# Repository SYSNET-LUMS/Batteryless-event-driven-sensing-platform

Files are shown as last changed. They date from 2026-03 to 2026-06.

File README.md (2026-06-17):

# Motion-Coupled Sensing: When the State Change Powers Its Own Sensing

A self-powered IoT platform that harvests kinetic energy from mechanical access events — bin lids, room doors, and office cabinet hinges — to power and transmit sensor readings with no batteries and no scheduled maintenance.

---

## How It Works

Objects whose state changes only through a mechanical action carry enough kinetic energy in that motion to power both a sensor reading and a LoRa uplink. The system wakes only when there is something to report, and the event itself supplies the energy to do it. There is no polling, no sleep schedule, and no battery to replace.

An electromagnetic harvester — a DC motor in generator mode driven through a compact gear train — is retrofitted to the hinge or lid mechanism without any structural modification to the host object.

## Repository Structure

```
├── firmware/
│   ├── sensor-node/                  # Sensor node and gateway firmware, packet-layout SVG
│   └── bin_unit_field_testing/       # Bin lid characterization firmware + serial data logger
├── hardware/
│   ├── harvestor_cad/                # STEP, STL, SLDPRT, DXF files; CAD modeling video
│   └── pcb/                          # PCB schematic, layout, EPRO project, netlist
├── bin_depth_analysis/
│   ├── Images/                       # Per-run averaged depth and RGB frames (run1–50)
│   └── Wall Masks/                   # Masked depth averages for wall-plane isolation (run1–15)
└── media/
    └── images/
        ├── bin-unit/                 # Bin unit build and deployment photos
        ├── door-unit/                # Door unit build photos
        ├── cabinet-unit/             # Cabinet unit build photos
        └── harvestor.png             # Harvester overview image
```

---

## Results at a Glance

| Deployment | Actuations | Transmission Reliability |
|:---|---:|---:|
| Waste Bins — 5 campus locations | 5,945 | **99.3%** |
| Room Doors | 1870 | **92%** |
| Office Cabinets | 1636 | **94%** |

---

## Harvester

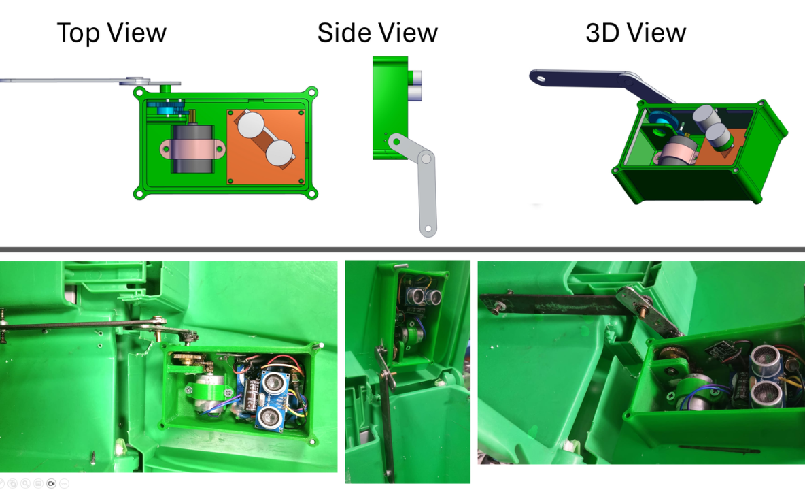
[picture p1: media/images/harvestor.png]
Harvester


| Parameter | Value |
|:---|:---|
| Generator | 24V DC motor (generator mode) |
| Gear Train | 3-stage spur, 1:42.6 ratio |
| Storage | 1000 µF capacitor |
| Gating | Mercury tilt switch + SS34 Schottky diode |

CAD source files (STEP, STL, SolidWorks SLDPRT, DXF drawings, and drawing PDF) are in [`hardware/harvestor_cad/`](hardware/harvestor_cad/).

---

## Sensor Node

| Block | Components |
|:---|:---|
| Sensing | HC-SR04 ultrasonic sensor |
| Compute | ATmega328P MCU, MP2307 buck converter (3V rail) |
| Communication | RA-02 LoRa module (Semtech SX1278) |

### PCB

| Schematic | Layout |
|:---:|:---:|
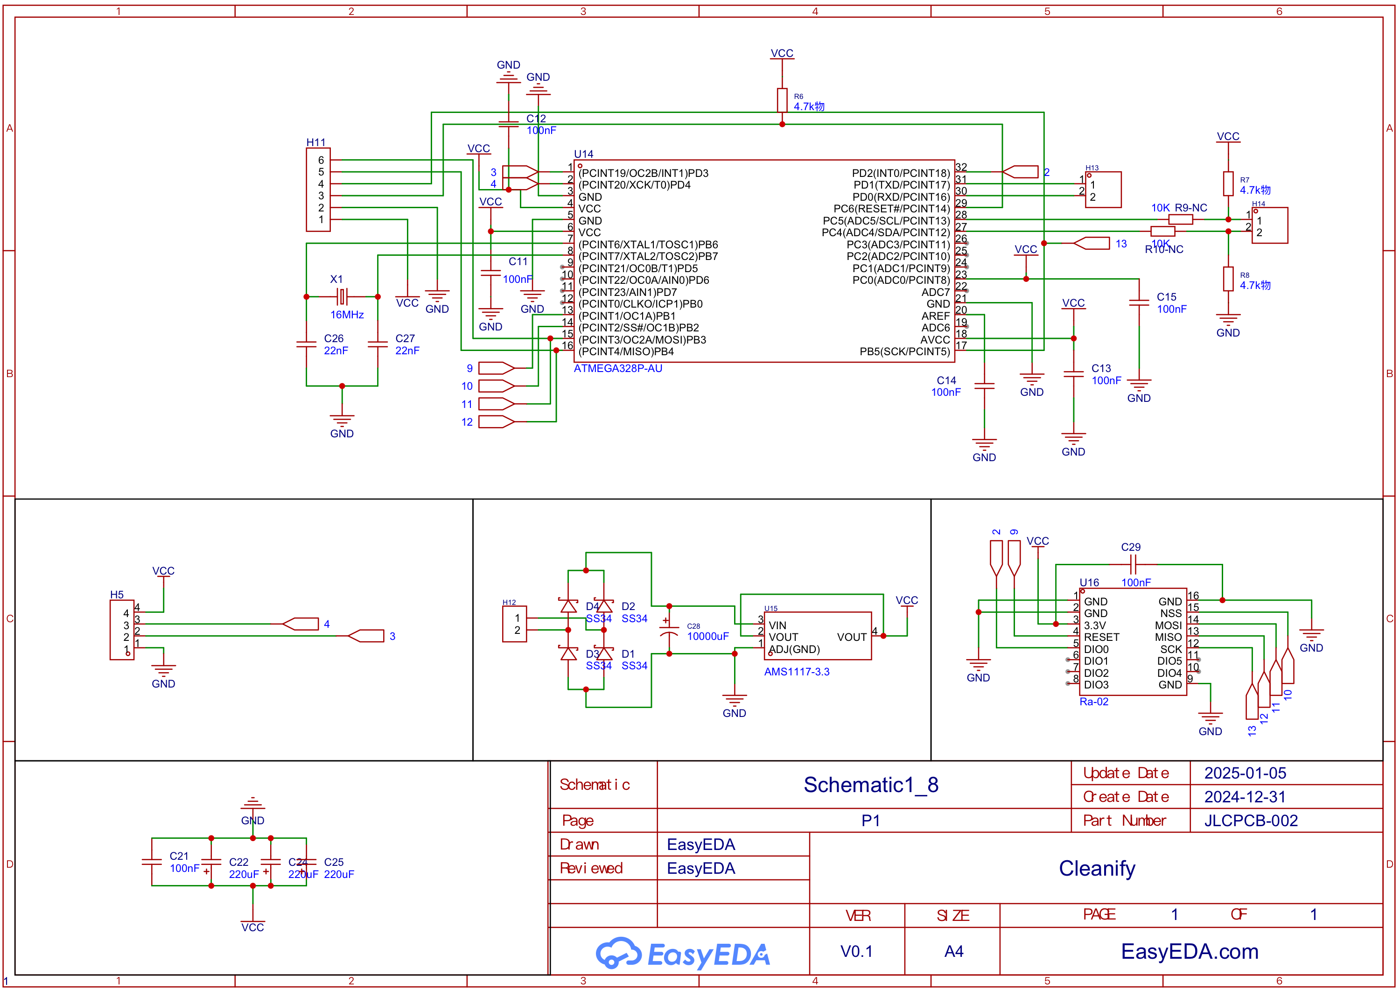
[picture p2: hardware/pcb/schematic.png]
Schematic
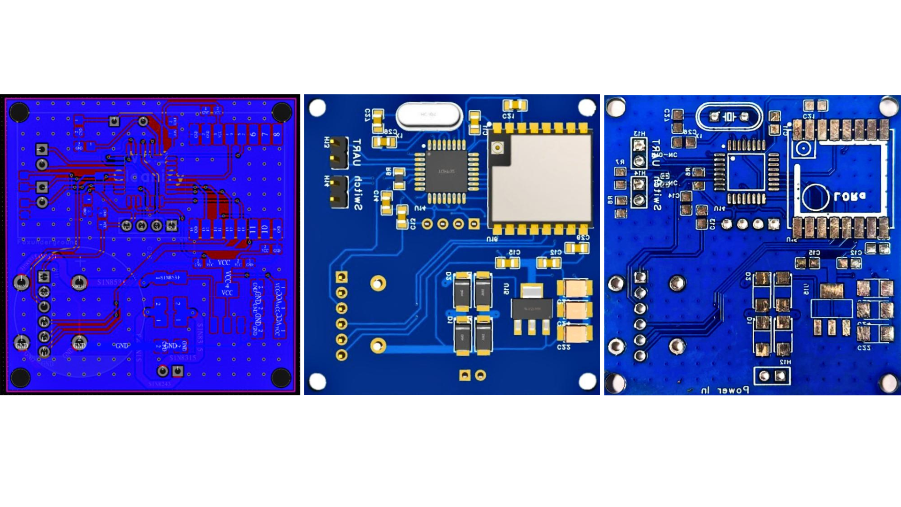
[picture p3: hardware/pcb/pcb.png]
PCB Layout
|  |  |

Design files (EPRO project, netlist, schematic PDF) are in [`hardware/pcb/`](hardware/pcb/).

---

## Form Factors

### Waste Bin

Measures fill level via ultrasonic ranging on every lid open. Deployed across 5 campus locations under real-world conditions (18–38°C, 40–85% humidity, occasional rainfall).

| | | |
|:---:|:---:|:---:|
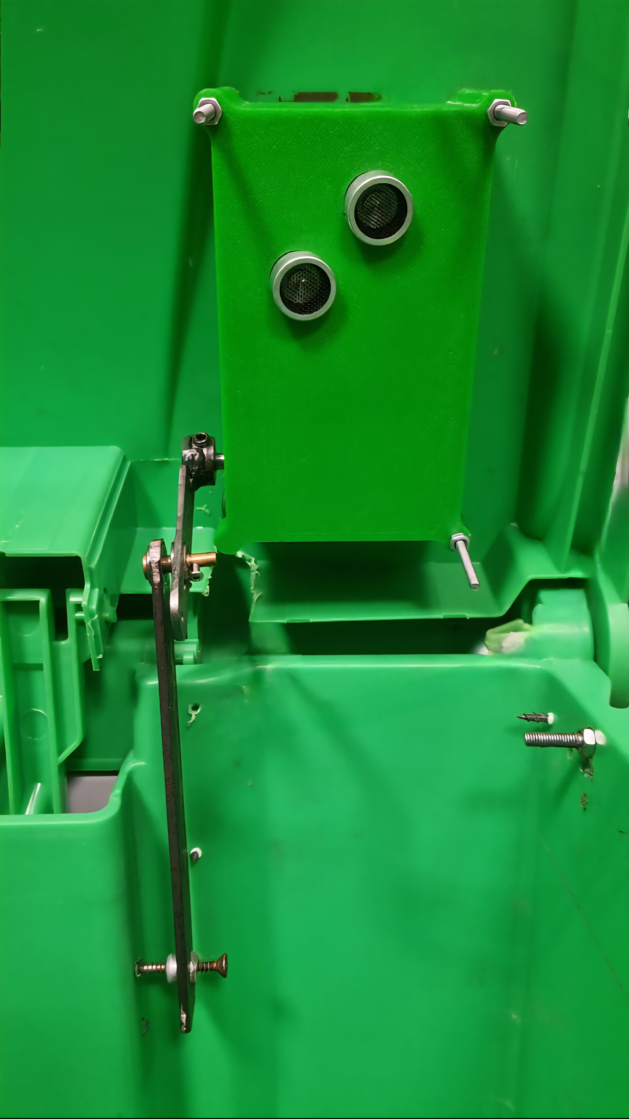
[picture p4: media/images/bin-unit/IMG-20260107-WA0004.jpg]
Bin unit
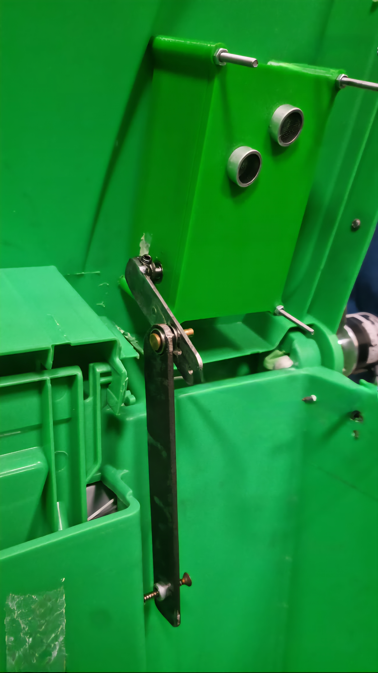
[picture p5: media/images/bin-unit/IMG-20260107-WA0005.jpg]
Bin unit
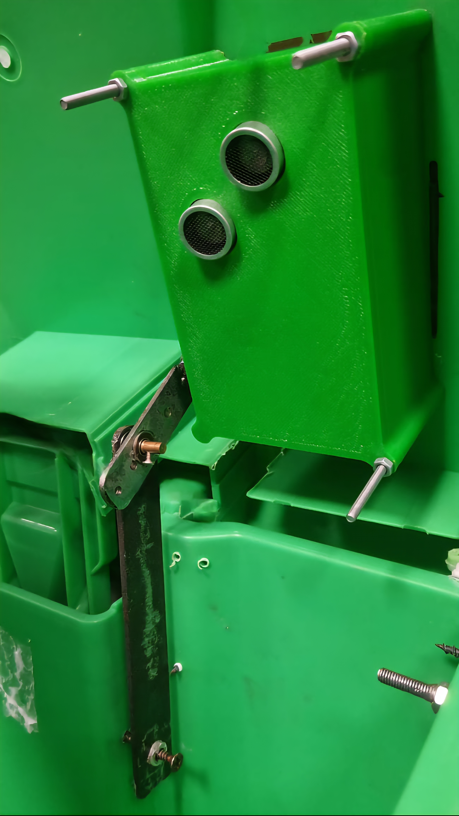
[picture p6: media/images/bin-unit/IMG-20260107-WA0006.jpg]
Bin unit
|  |  |  |
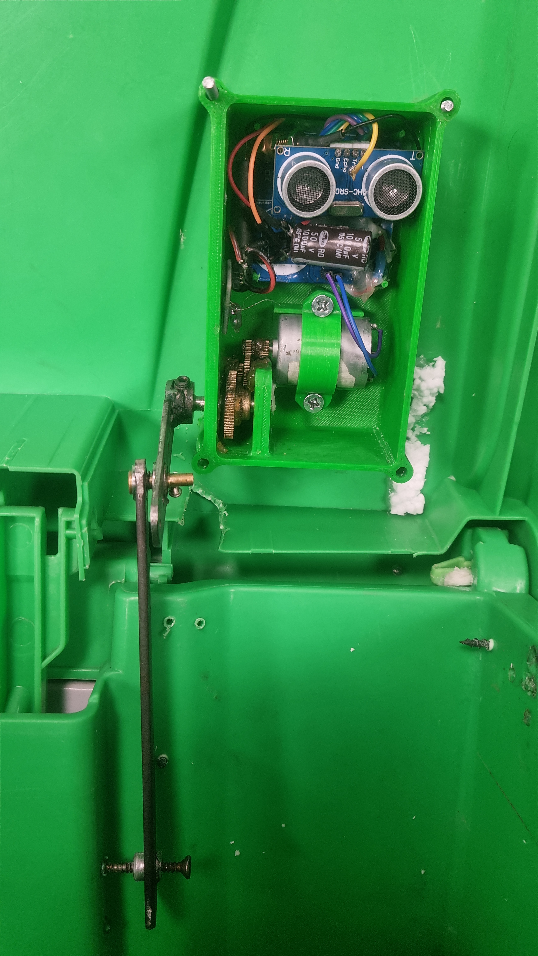
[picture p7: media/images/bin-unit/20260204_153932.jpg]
Bin unit
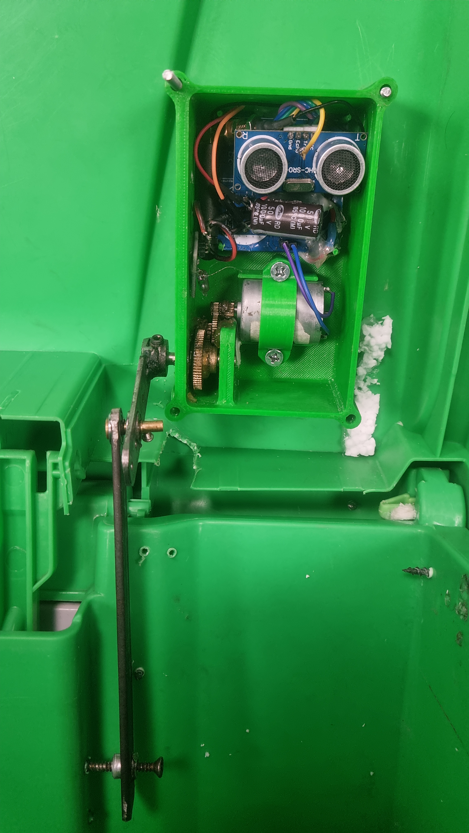
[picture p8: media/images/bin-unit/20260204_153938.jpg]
Bin unit
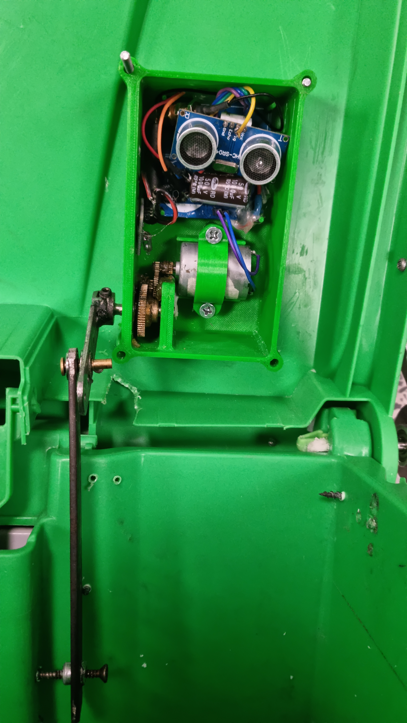
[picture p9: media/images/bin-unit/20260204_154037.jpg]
Bin unit
|  |  |  |

### Room Door

Retrofit mounted to the door hinge. Reports each door swing as an access event.

| | | | |
|:---:|:---:|:---:|:---:|
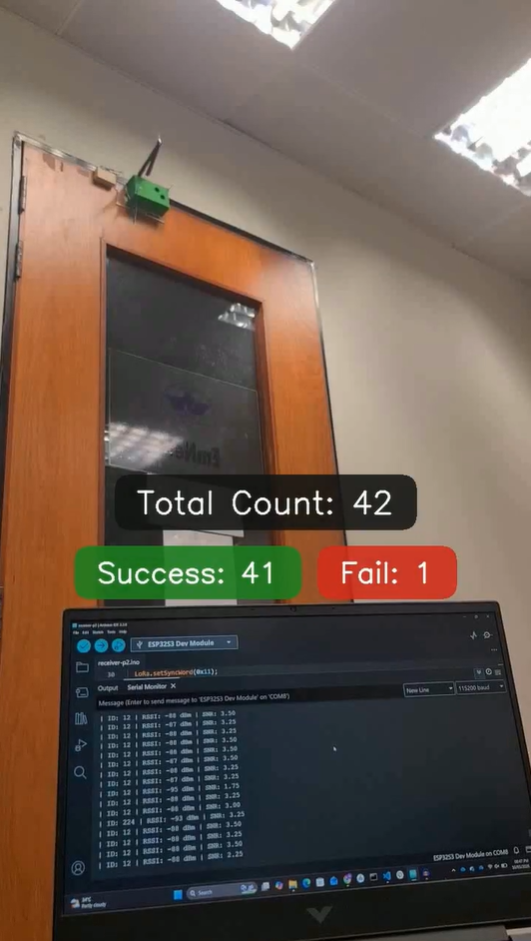
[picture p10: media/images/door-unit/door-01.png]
Door unit
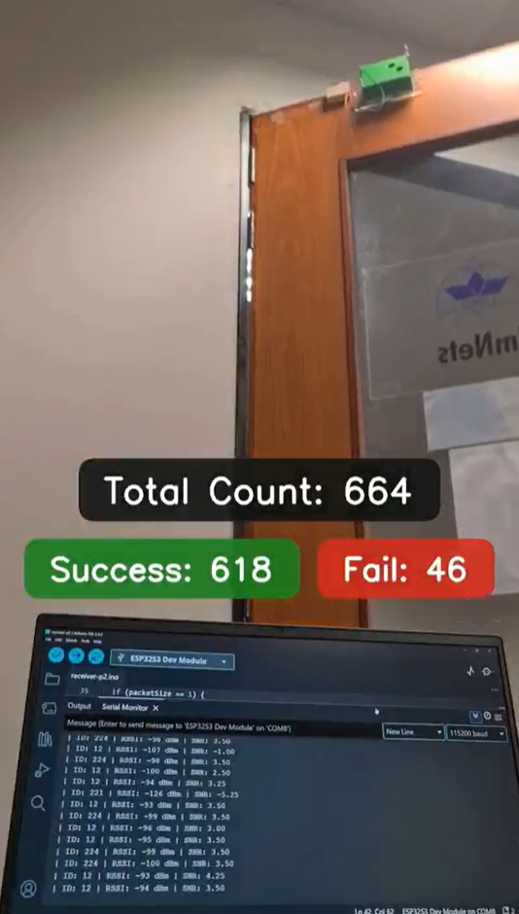
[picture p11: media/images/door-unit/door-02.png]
Door unit
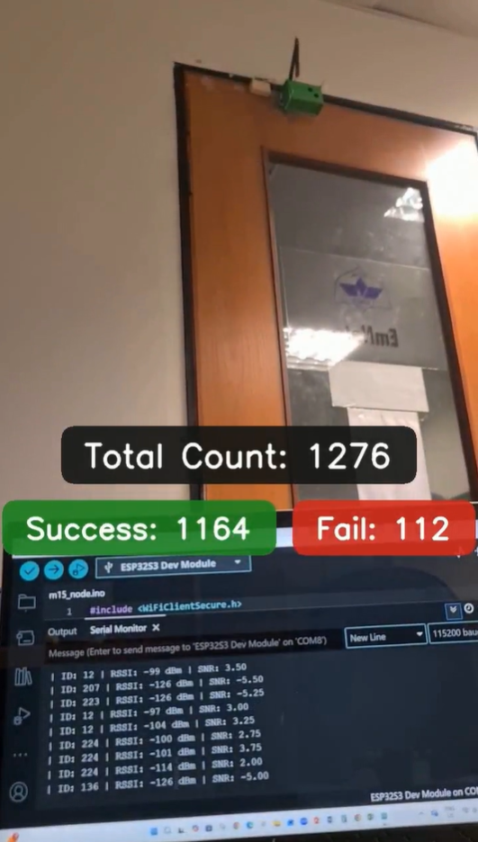
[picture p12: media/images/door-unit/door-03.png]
Door unit
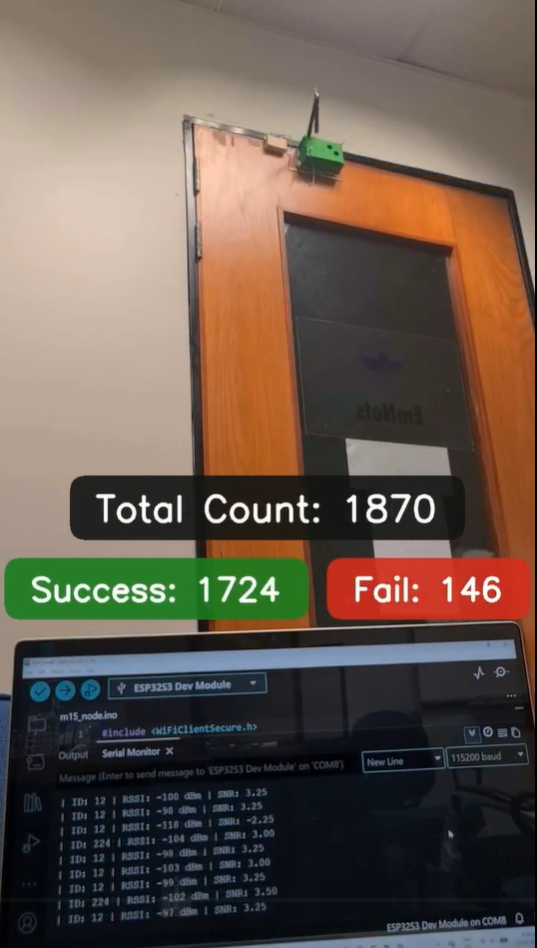
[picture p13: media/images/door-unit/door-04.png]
Door unit
|  |  |  |  |

[Watch full trial on Drive](https://shorturl.at/BA1z8)

### Office Cabinet

Harvester mounted on the cabinet hinge. Reports each cabinet open as an access event.

| | | | |
|:---:|:---:|:---:|:---:|
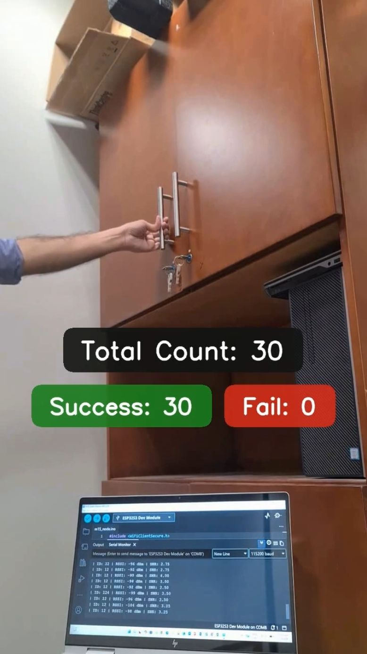
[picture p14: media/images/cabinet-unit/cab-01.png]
Cabinet unit
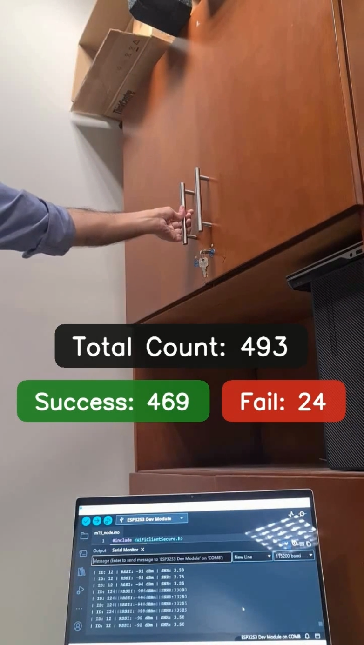
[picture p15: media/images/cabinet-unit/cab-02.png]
Cabinet unit
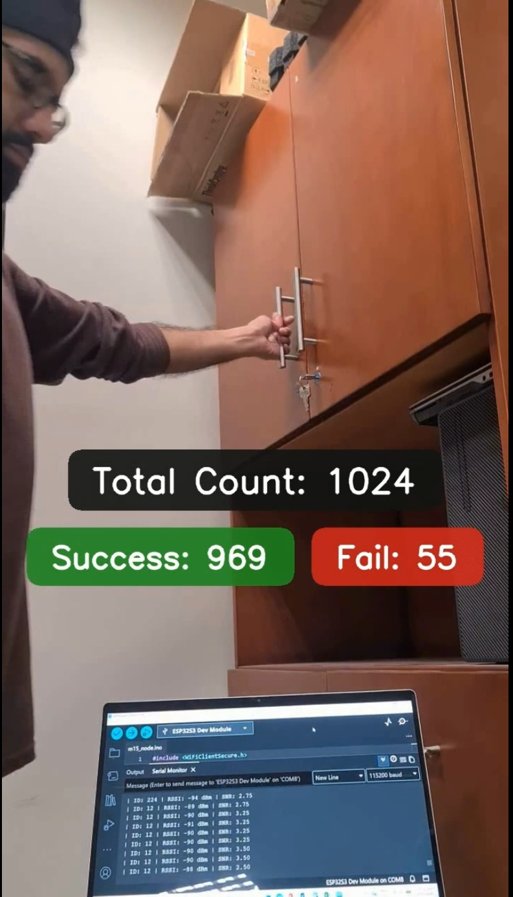
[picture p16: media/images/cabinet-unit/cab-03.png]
Cabinet unit
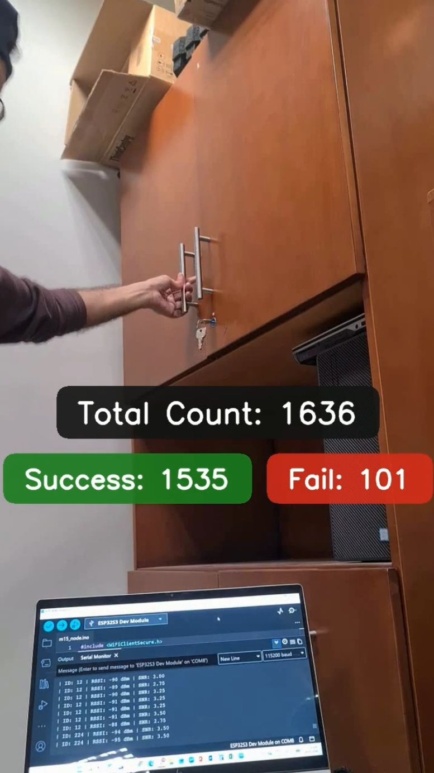
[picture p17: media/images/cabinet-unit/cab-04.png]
Cabinet unit
|  |  |  |  |

[Watch full trial on Drive](https://shorturl.at/NqOQz)

---

## Harvester Stress Testing — 10,000 Iterations

Standalone module run to characterise mechanical durability before field deployment.

| | | | |
|:---:|:---:|:---:|:---:|
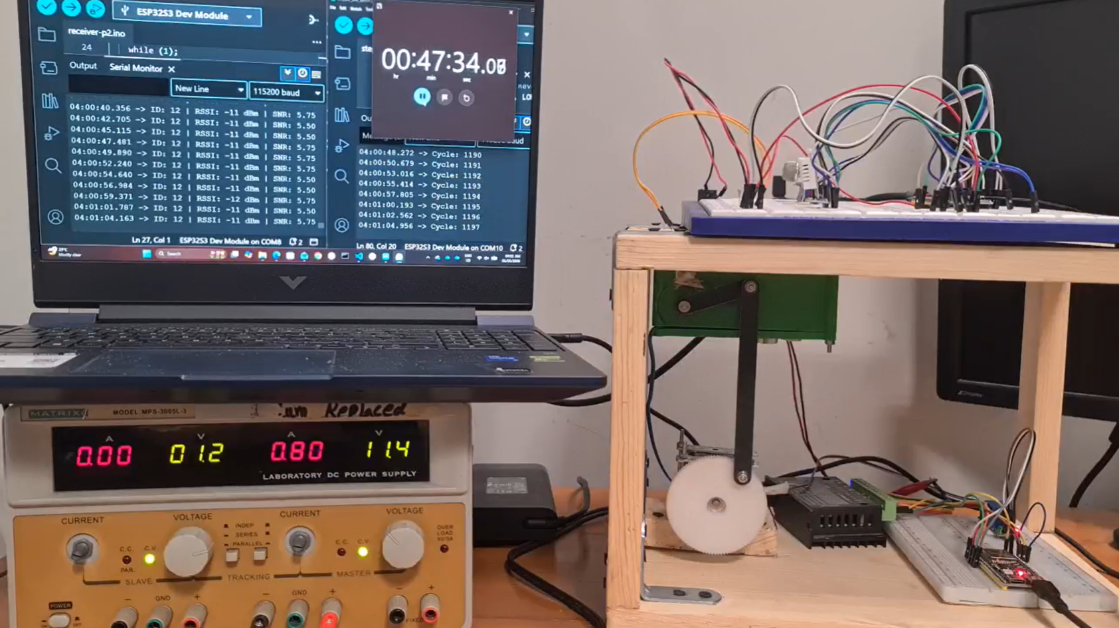
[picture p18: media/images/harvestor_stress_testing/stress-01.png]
Stress test
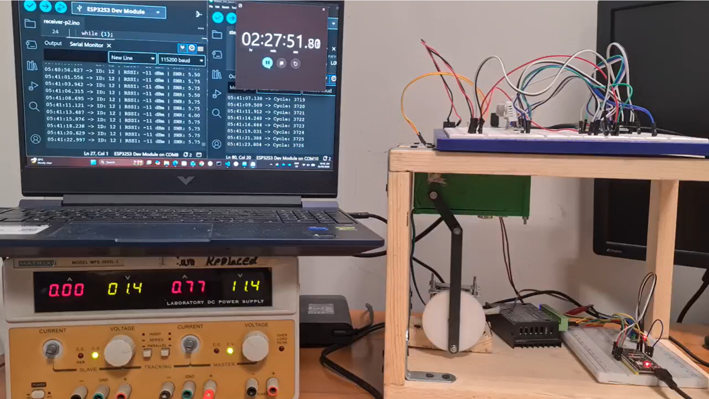
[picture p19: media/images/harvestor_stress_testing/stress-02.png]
Stress test
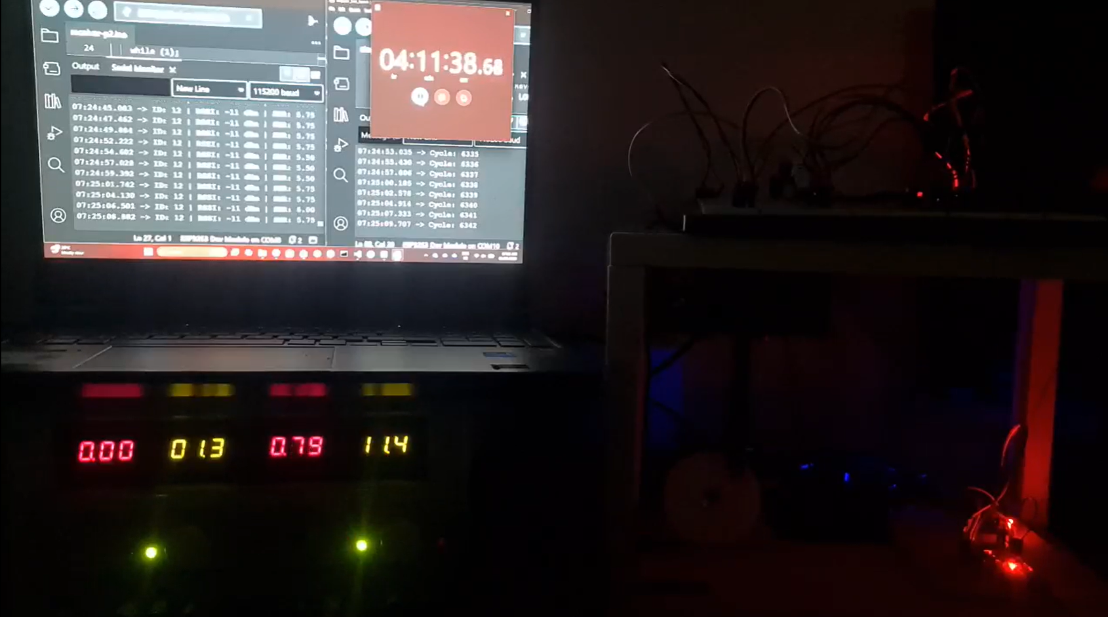
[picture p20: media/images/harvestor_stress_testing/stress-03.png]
Stress test
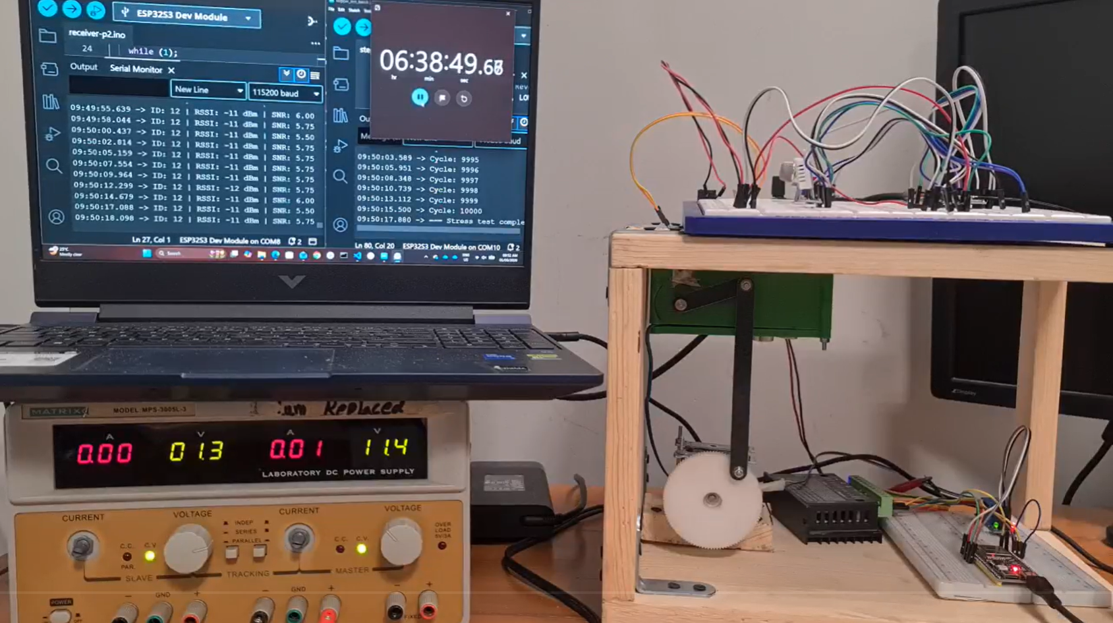
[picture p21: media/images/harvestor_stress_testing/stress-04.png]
Stress test
|  |  |  |  |

[Watch full test on Drive](https://tinyurl.com/yn5ekxc2)

---

## Firmware

| File | Purpose |
|:---|:---|
| [`firmware/sensor-node/transmitter-p2.ino`](firmware/sensor-node/transmitter-p2.ino) | Sensor node: MCU boot, ultrasonic sensing, LoRa uplink |
| [`firmware/sensor-node/receiver-p2.ino`](firmware/sensor-node/receiver-p2.ino) | Gateway receiver: captures LoRa packets and forwards upstream |
| [`firmware/bin_unit_field_testing/data_collection/data_collection.ino`](firmware/bin_unit_field_testing/data_collection/data_collection.ino) | Bin characterization: logs lid angle, duration, and encoder data |
| [`firmware/bin_unit_field_testing/data_collection.py`](firmware/bin_unit_field_testing/data_collection.py) | Serial data logger: receives and stores lid interaction records |

### LoRa Packet Layout

LoRa Packet Layout

| Field | Size | Description |
|:---|:---:|:---|
| `device_id` | 2 bytes | Unique unit identifier |
| `fill_level` | 2 bytes | HC-SR04 distance reading in cm (bin deployments) |
| `timestamp` | 4 bytes | Unix timestamp of actuation |
| `rssi` | 1 byte | Received signal strength (gateway-side) |

LoRa physical layer: SF10, BW 125 kHz, CR 4/8, TX power 20 dBm.

---

## Bin Field Deployment

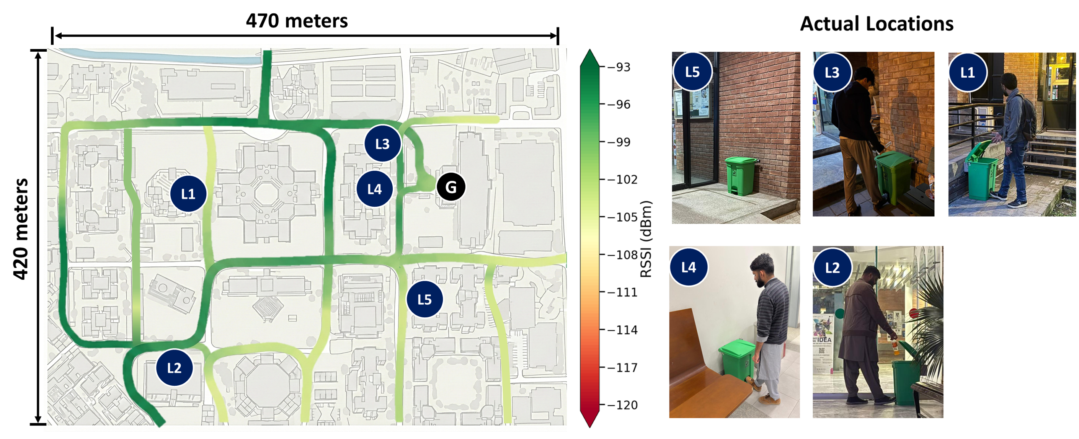
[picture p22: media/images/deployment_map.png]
Deployment Map


Five units deployed sequentially across campus:

| Location | Traffic Profile |
|:---|:---|
| L1 — Library | High traffic during academic hours |
| L2 — Business School | Moderate–high traffic, peaks at class transitions |
| L3 — Cafe Entrance | High traffic concentrated around meal times |
| L4 — Cafeteria | High traffic, rapid successive actuations |
| L5 — Dormitories | Variable traffic, peaks morning and evening |

Post-deployment inspection across all units: zero water ingress, no corrosion, no mechanical degradation.

---

## Bin Depth Analysis

50 depth + RGB recording runs captured inside the bin to characterise interior geometry and validate fill-level sensing. Each run produces a time-averaged depth frame and a corresponding RGB frame; a wall-mask subset (runs 1–15) isolates the bin wall plane for background calibration.

| RGB Average | Depth Average |
|:---:|:---:|
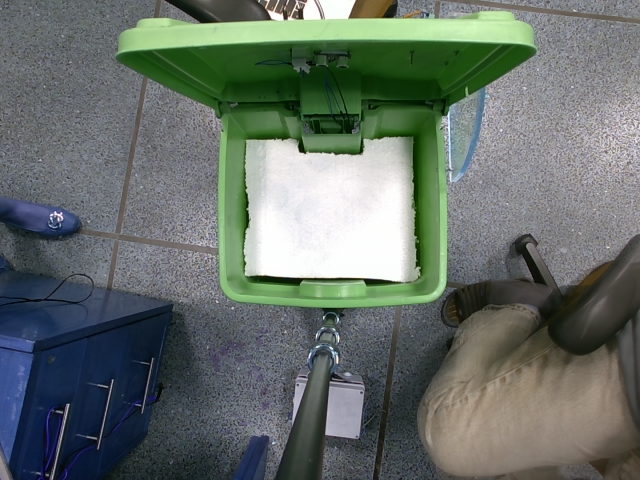
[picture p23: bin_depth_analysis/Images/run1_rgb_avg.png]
Run 1 RGB
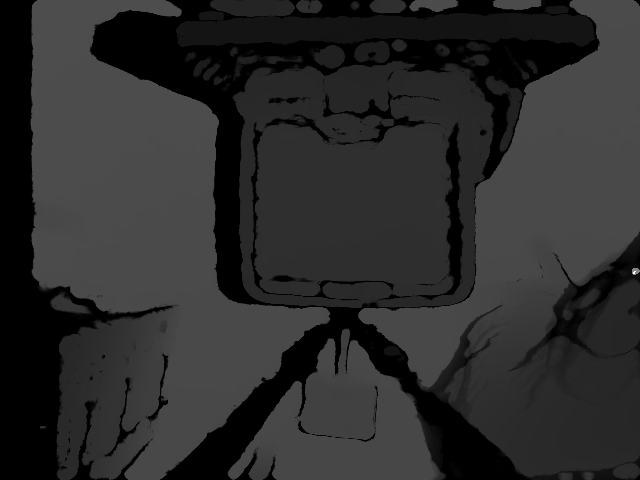
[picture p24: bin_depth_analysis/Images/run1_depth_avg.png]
Run 1 Depth
|  |  |
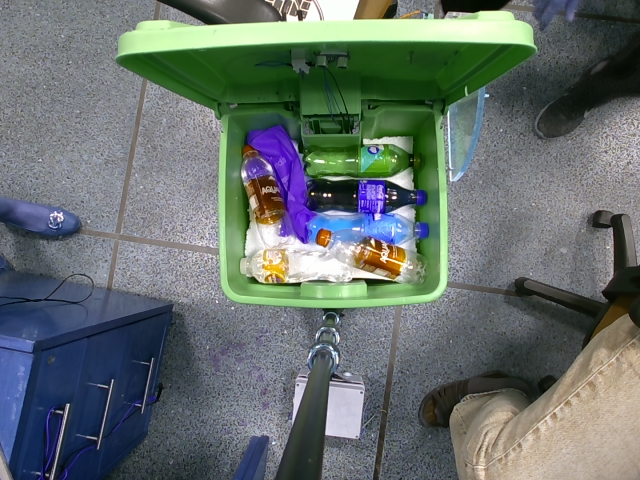
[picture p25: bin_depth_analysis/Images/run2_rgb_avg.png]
Run 2 RGB
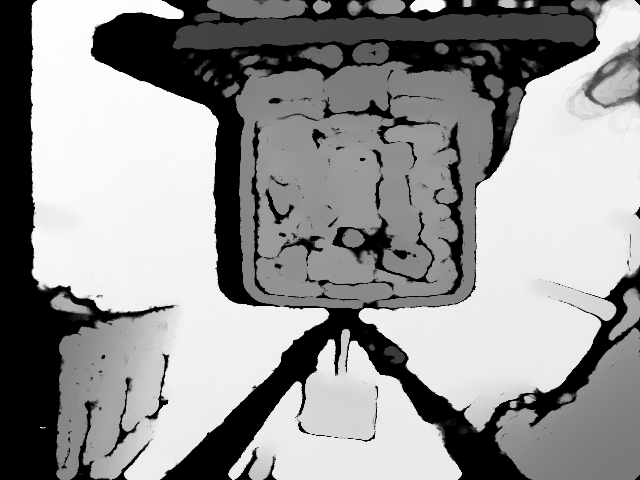
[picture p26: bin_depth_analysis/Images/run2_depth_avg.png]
Run 2 Depth
|  |  |
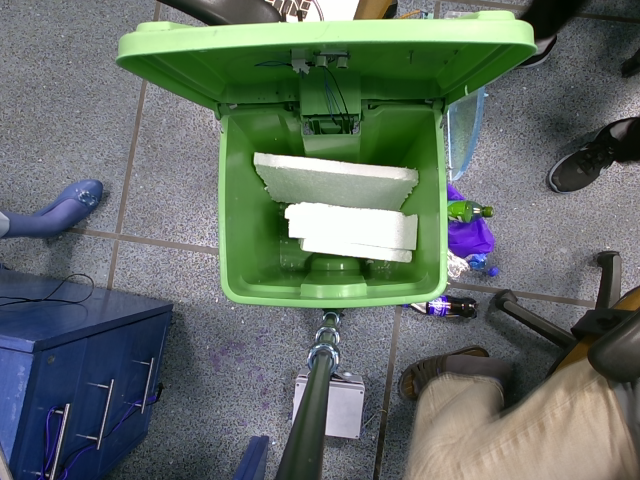
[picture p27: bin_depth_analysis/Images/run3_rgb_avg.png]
Run 3 RGB
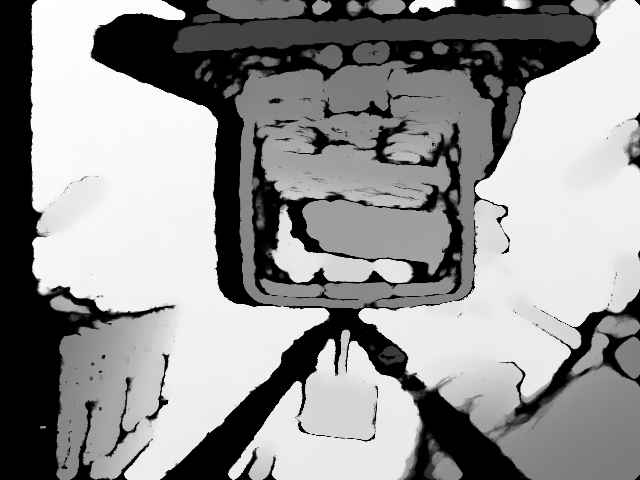
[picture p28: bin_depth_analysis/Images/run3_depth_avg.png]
Run 3 Depth
|  |  |

Raw `.bag` recordings (50 runs): [Download from SharePoint](https://pern-my.sharepoint.com/:f:/g/personal/baig_muhammad_lums_edu_pk/IgDPkcKNrldGRr3JelqhKEQdAa63hqt8INTA9sXD9E0Jkpo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)

---

## Setup & Usage

**Requirements:** Arduino IDE/CLI with ATmega328P and ESP32 board support, Python 3.x with `pyserial`.

```bash
git clone <repository-url>
pip install pyserial
```

Flash sensor node and gateway receiver:

```bash
arduino-cli upload --fqbn arduino:avr:pro --port /dev/ttyUSB0 firmware/sensor-node/transmitter-p2.ino
arduino-cli upload --fqbn arduino:avr:pro --port /dev/ttyUSB1 firmware/sensor-node/receiver-p2.ino
```

For bin lid characterization (ESP32-based):

```bash
arduino-cli upload --fqbn esp32:esp32:esp32 --port /dev/ttyUSB0 firmware/bin_unit_field_testing/data_collection/data_collection.ino
python firmware/bin_unit_field_testing/data_collection.py
```

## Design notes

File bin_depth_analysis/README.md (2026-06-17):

# Analysis — Depth & Ultrasonic Sensor Characterization

Complete analysis pipeline for RealSense depth camera characterization and HC-SR04 ultrasonic sensor validation across 50 field deployment runs.

## Overview

This folder contains the full analysis workflow for the Batteryless Event-Driven Sensing Platform's bin fill-level sensing system. The system combines:
- **RealSense D455** depth camera for ground truth fill-level measurement
- **HC-SR04** ultrasonic ranging sensor for deployment use
- **50 validation runs** across real-world field conditions

## Folder Structure

```
bin_depth_analysis/
├── README.md (this file)
├── rectangle_coordinates.json       # ROI definitions for all 50 runs
│
├── notebooks/
│   └── depth_3d_analysis_50runs.ipynb     # Main analysis notebook
│                                           # - Processes all 50 ROS bag files
│                                           # - Extracts RealSense depth/RGB frames
│                                           # - Generates 2D & 3D visualizations
│
├── [raw_runs/ — hosted externally]  # Raw sensor data (ROS bag format)
│   ├── run1.bag through run50.bag   # 50 bags, ~11 GB total
│   │                                # Each contains:
│   │                                # - RealSense D455 depth (640×480 @30fps, 16-bit)
│   │                                # - Synchronized RGB frames (640×480 @30fps)
│   │                                # - Camera intrinsics & timestamps
│   └── Download: https://pern-my.sharepoint.com/:f:/g/personal/baig_muhammad_lums_edu_pk/IgDPkcKNrldGRr3JelqhKEQdAa63hqt8INTA9sXD9E0Jkpo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
│
├── baseline_ultrasonic/             # HC-SR04 sensor calibration
│   └── baseline_ultrasonic_values.txt       # Original measurement file
│
├── Images/                          # Averaged sensor frames (50 runs)
│   ├── run1_rgb_avg.png through run50_rgb_avg.png      (RGB averages)
│   └── run1_depth_avg.png through run50_depth_avg.png  (Depth averages)
│
├── Wall Masks/                      # Wall exclusion masks (15 runs)
│   ├── run1_depth_avg.png through run15_depth_avg.png
│   │                                # Binary masks for interior vs wall regions
│   │                                # Used to exclude container walls from analysis
│   └── ...
│
└── results/
    └── run_outputs/                 # Output visualizations (50 runs)
        ├── run1_output_1.png through run50_output_1.png
        │                            # 2D matplotlib figures showing:
        │                            # - Left: Depth heatmap (viridis colormap)
        │                            # - Right: RGB ROI image
        │                            # ~200-450 KB each, ready for reports
        └── ...
```

## Data Formats

### ROS Bag Files (raw_runs/)
Raw recordings are hosted externally due to size (~11 GB total). [Download from SharePoint](https://pern-my.sharepoint.com/:f:/g/personal/baig_muhammad_lums_edu_pk/IgDPkcKNrldGRr3JelqhKEQdAa63hqt8INTA9sXD9E0Jkpo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)

Binary ROS message format containing timestamped sensor data. Extract with:
```bash
rosbag info run1.bag
rosbag play run1.bag
```

### ROI Coordinates (rectangle_coordinates.json)
Region-of-Interest definitions for depth and RGB crops per run:
```json
{
  "run1": {
    "depth": [x1, y1, x2, y2],    // RealSense depth ROI (pixel coords)
    "rgb": [x1, y1, x2, y2]       // RealSense RGB ROI (pixel coords)
  }
}
```

### Output Images (run_outputs/)
PNG files from notebook 2D plot outputs. Two per run:
- `run1_output_1.png`: 2D depth map + RGB ROI side-by-side
  - Shows processed depth with wall exclusion applied
  - Includes depth colorbar (0–563.2 mm range)

### Ultrasonic Calibration (baseline_ultrasonic/)

**ultrasonic_vs_ground_truth.csv** — 15-run validation:
```
Run,Ground_Truth_mm,Ultrasonic_Raw_mm,Ultrasonic_Bias_Corrected_mm,Error_mm,Abs_Error_mm
run1,154.5,166.7,173.4,18.9,18.9
run2,122.4,144.4,151.1,28.7,28.7
...
```

**Accuracy Summary:**
- Median Absolute Error: **31.5 mm**
- Mean Absolute Error: **49.9 mm**
- Systematic Bias: **-6.7 mm** (subtract from raw readings)
- Range of depths covered: 107.3–419.4 mm (ground truth)

## Analysis Notebook

### File
`notebooks/depth_3d_analysis_50runs.ipynb`

### Contents
1. **Setup (Cells 0–4)**
   - Imports & configuration
   - Load ultrasonic baseline values (all 50 runs)
   - Load ROI coordinates from JSON
   - Helper function definitions

2. **Per-Run Analysis (Cells 5–107)**
   - 50 sections (one per run)
   - Each section:
     - Loads .bag file
     - Extracts depth frames via pyrealsense2
     - Computes average depth
     - Crops to ROI, filters invalid ranges (600–2000 mm)
     - Applies wall exclusion mask
     - Generates 2D matplotlib figure (depth + RGB)
     - Generates interactive 3D plotly surface
     - Outputs fill-level estimate and error metrics

3. **Wall Exclusion Algorithm**
   - Loads pre-computed wall masks from `Wall Masks/`
   - Binary mask: 1 = interior (include), 0 = wall (exclude)
   - Reduces outlier spikes from container walls

4. **Output Visualization**
   - 2D plot: Depth heatmap + RGB ROI
   - 3D plot: Interactive surface with reference planes
     - Viridis colormap for depth
     - Crimson plane: ultrasonic reading (if available)
     - Orange plane: depth map average (ground truth)

## Key Measurements

### Per-Run Base Depths
- **Group A (run1–15):** 676 mm
- **Group B (run16):** 731 mm
- **Group C (run17–50):** 780 mm

These constants are used to convert fill-level readings (in cm) to absolute depth.

### Ultrasonic Readings
All 50 runs stored in ULTRASONIC_CM dict within notebook:
```python
ULTRASONIC_CM = {
    'run1': 12.95,  'run2': 10.75, ...  'run50': 4.9
}
```

## Workflow

```
raw_runs/ .bag files  (download from SharePoint)
    ↓
[Extract depth + RGB frames with pyrealsense2]
    ↓
[Crop to ROI using rectangle_coordinates.json]
    ↓
[Filter invalid depth range (600–2000 mm)]
    ↓
[Apply wall exclusion masks from Wall Masks/]
    ↓
[Compute average depth within interior region]
    ↓
[Generate depth map image]
    ↓
[Output: PNG + 3D visualization]
    ↓
results/run_outputs/
```

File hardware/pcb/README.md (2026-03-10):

# PCB Design

Designed in EasyEDA Pro Edition and manufactured by JLCPCB on a 2-layer FR4 board.

## PCB

PCB Layout

## Schematic

Schematic

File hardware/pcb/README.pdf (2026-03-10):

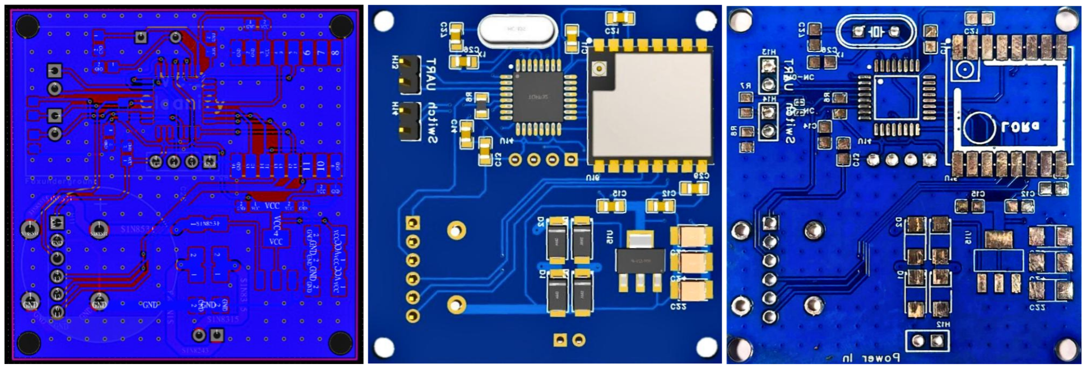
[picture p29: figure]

P R OF ESSEUR : M . DA R OS | BT S SIO B ORDEAUX - LYCÉ E GUSTAVE E I F F E L
✦ 1 / 2 ✦

# PCB Design

Designed in EasyEDA Pro Edition and manufactured by JLCPCB on a 2-layer FR4 board.

# PCB

# Schematic

P

R


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
E I F

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
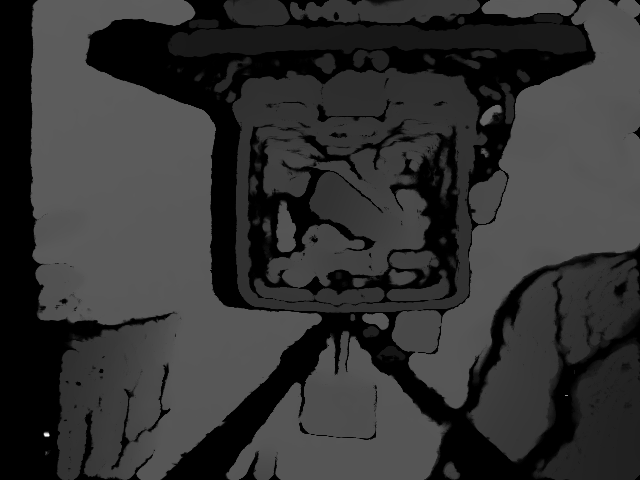
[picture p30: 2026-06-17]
bin_depth_analysis/Images/run10_depth_avg.png

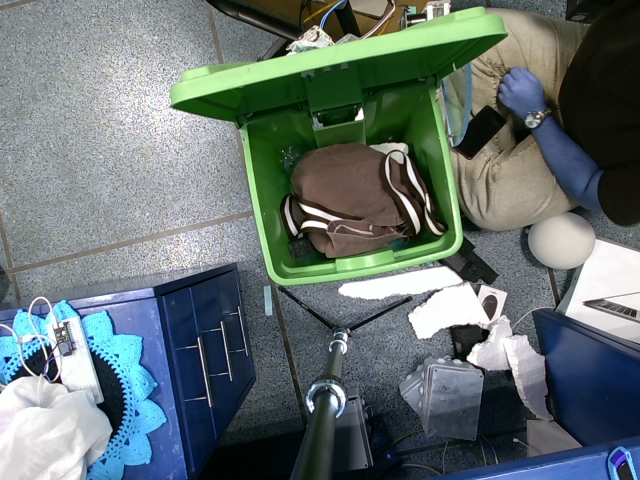
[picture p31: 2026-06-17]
bin_depth_analysis/Images/run45_rgb_avg.png

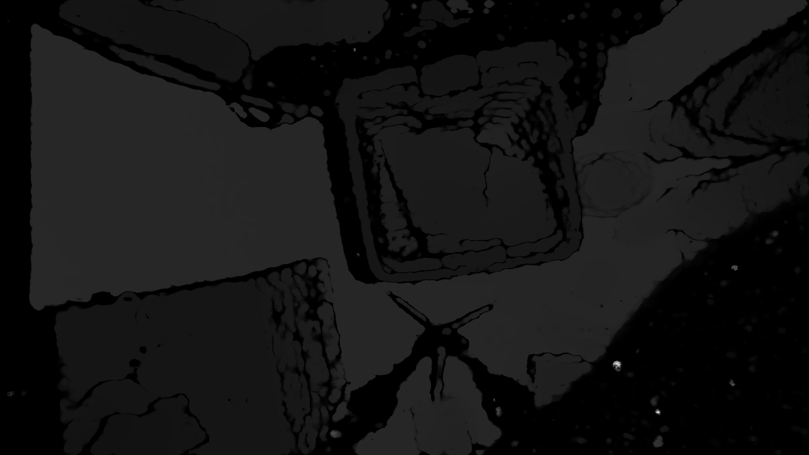
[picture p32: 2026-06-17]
bin_depth_analysis/Images/run35_depth_avg.png

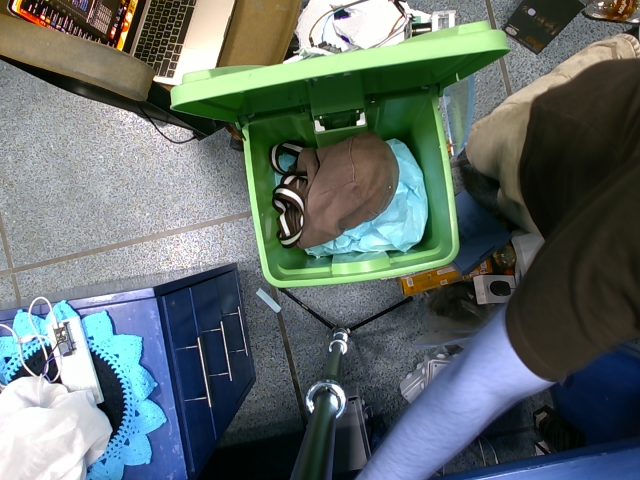
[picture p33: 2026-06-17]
bin_depth_analysis/Images/run28_rgb_avg.png

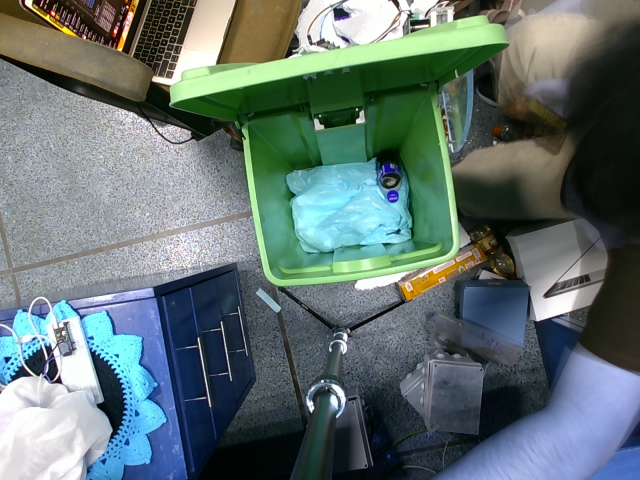
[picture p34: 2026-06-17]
bin_depth_analysis/Images/run30_rgb_avg.png

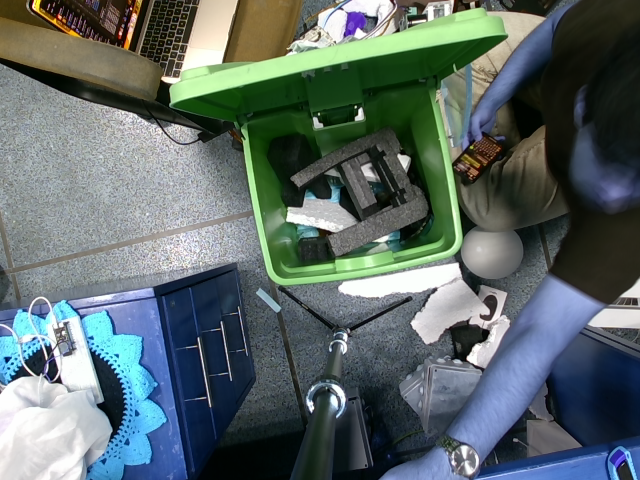
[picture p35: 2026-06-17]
bin_depth_analysis/Images/run43_rgb_avg.png

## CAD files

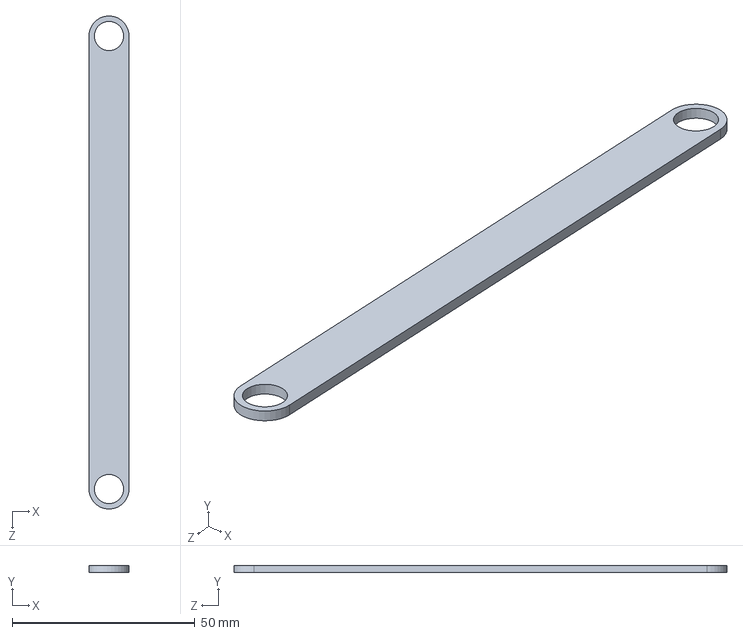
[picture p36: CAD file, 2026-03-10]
hardware/harvestor_cad/harvestor/13.5x1.1(8mm).SLDPRT
11.0 x 2.00 x 135.0 mm

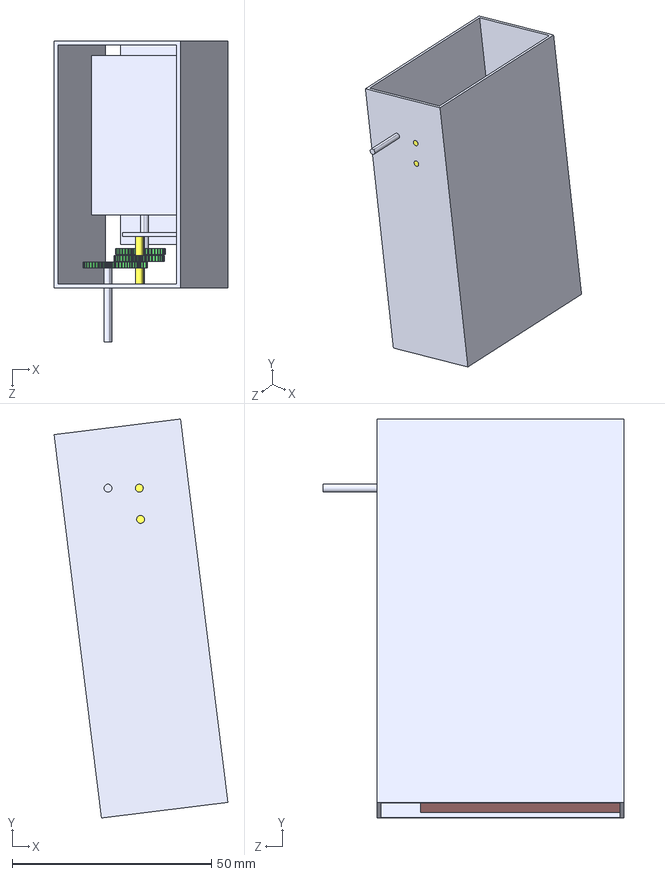
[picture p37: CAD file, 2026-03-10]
hardware/harvestor_cad/harvestor_SourceFile.STEP
43.7 x 100.2 x 75.5 mm
spur gear_am12_Metric - Spur gear 0.3M 40T 20PA 1.5FW ---S40N75H50L2N x 3
spur gear_am12_Metric - Spur gear 0.3M 12T 20PA 1.5FW ---S12N75H50L2N x 3
shaft of gear
Box of gear train
Shaft2 x 2
Motor
Holder plate
PCB

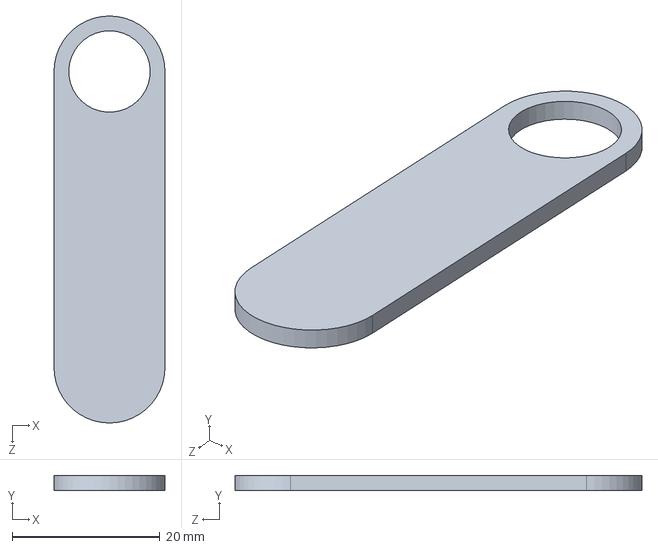
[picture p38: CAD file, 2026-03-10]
hardware/harvestor_cad/harvestor/5.5x1.5(1.1cm).SLDPRT
15.0 x 2.00 x 55.0 mm

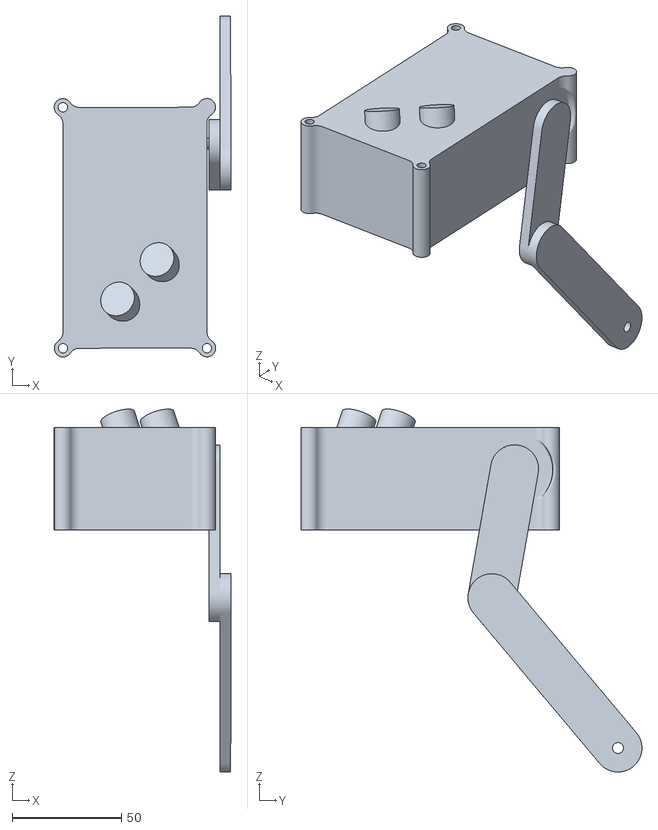
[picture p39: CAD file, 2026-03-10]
hardware/harvestor_cad/harvestor_SourceFileV1.0.stl
81.0 x 156.4 x 166.5

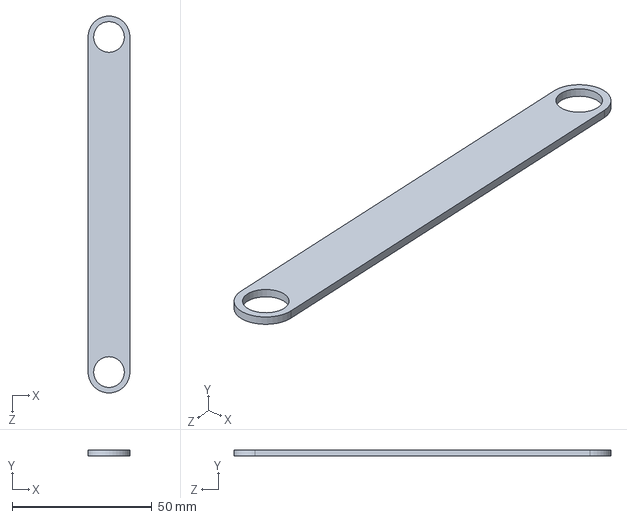
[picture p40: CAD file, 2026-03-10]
hardware/harvestor_cad/harvestor/13.5x1.5(1.1mm).SLDPRT
15.0 x 2.00 x 135.0 mm

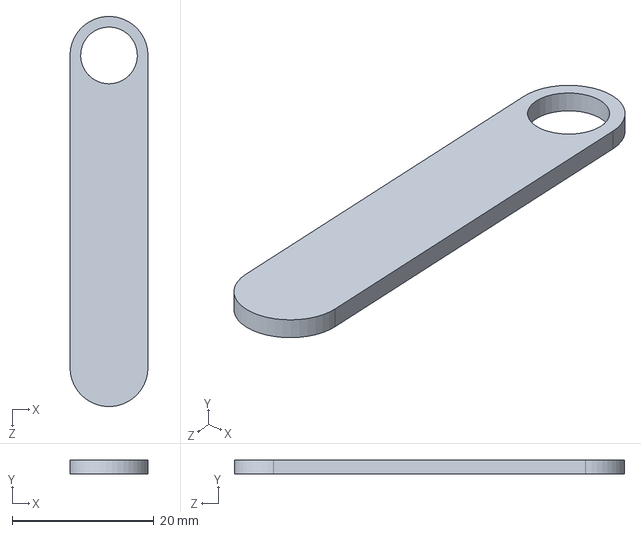
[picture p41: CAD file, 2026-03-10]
hardware/harvestor_cad/harvestor/5.5x1.1(8mm).SLDPRT
11.0 x 2.00 x 55.0 mm

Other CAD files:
hardware/harvestor_cad/harvestor/13.5x1.1(8mm).DXF
hardware/harvestor_cad/harvestor/13.5x1.5(1.1mm).DXF
hardware/harvestor_cad/harvestor/5.5x1.1(8mm).DXF
hardware/harvestor_cad/harvestor/5.5x1.5(1.1cm).DXF

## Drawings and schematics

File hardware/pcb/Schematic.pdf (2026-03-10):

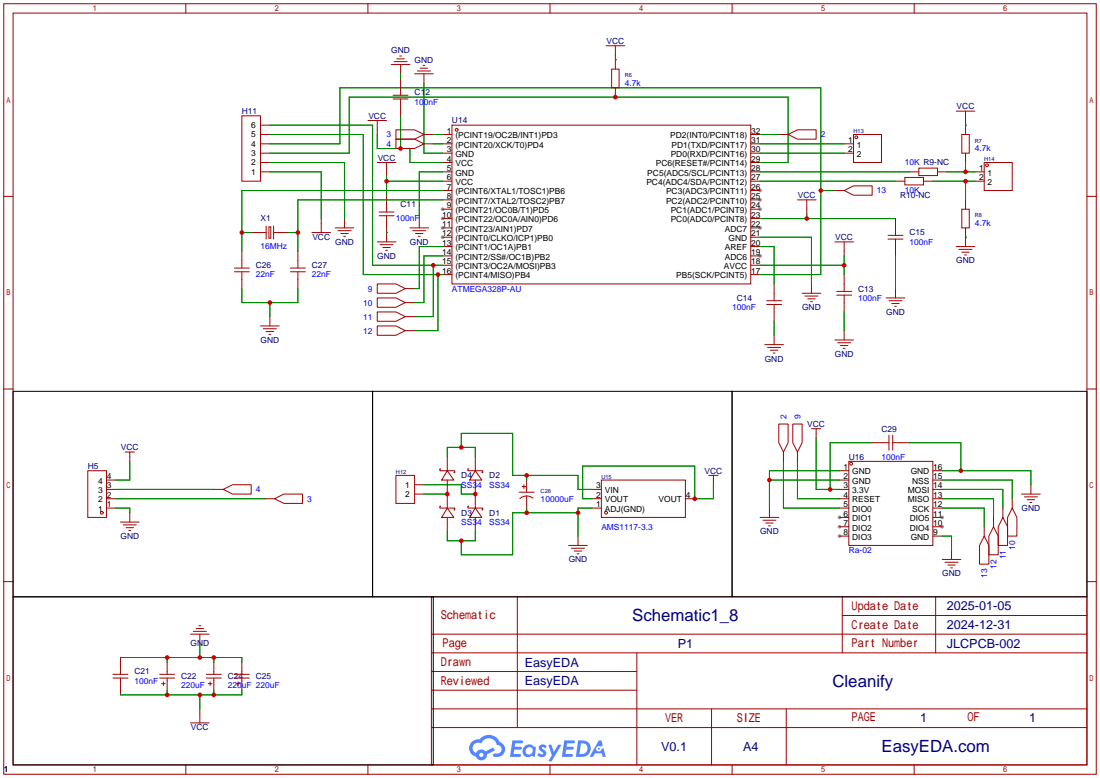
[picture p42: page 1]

VCC

DIO4 10 DIO5 11 SCK 12 MISO 13 MOSI 14 NSS 15 GND 16

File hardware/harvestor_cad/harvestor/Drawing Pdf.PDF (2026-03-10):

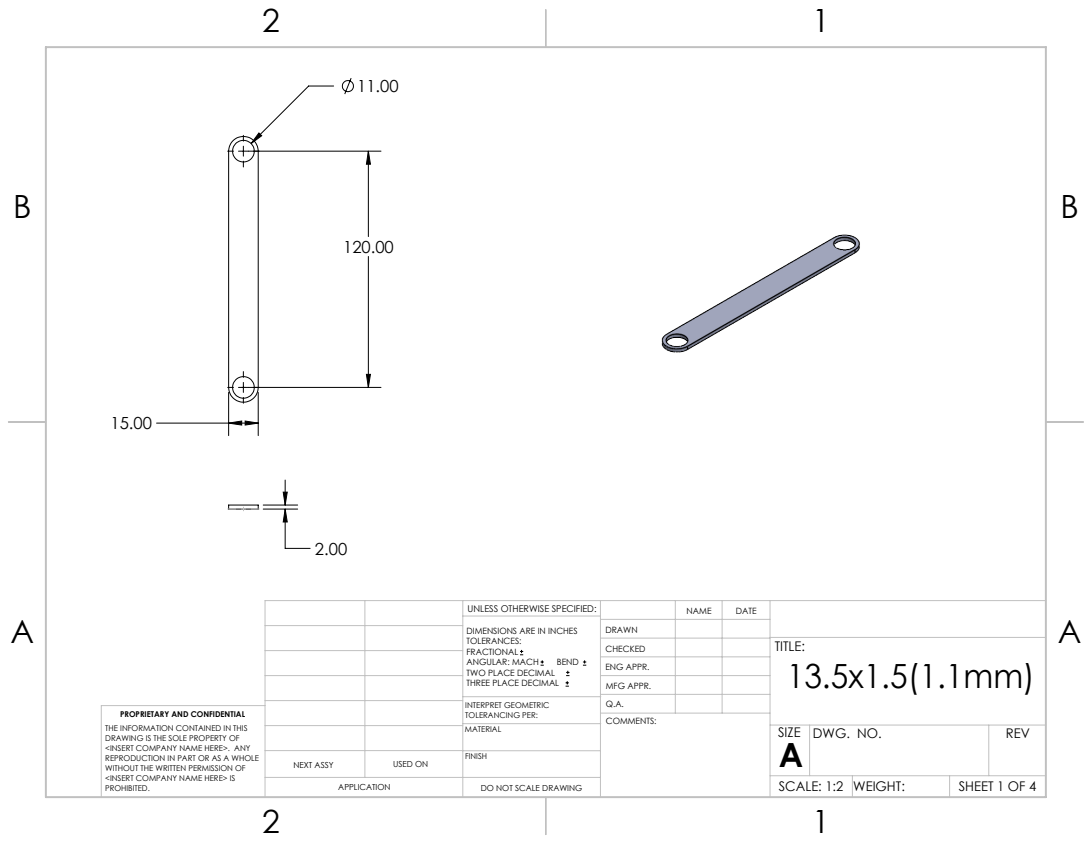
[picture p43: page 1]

UNLESS OTHERWISE SPECIFIED: | | NAME | DATE
DIMENSIONS ARE IN INCHES TOLERANCES: FRACTIONAL ANGULAR: MACH BEND TWO PLACE DECIMAL THREE PLACE DECIMAL | DRAWN

CHECKED | | | TITLE: 13.5x1.5(1.1mm)

ENG APPR.
MFG APPR.

INTERPRET GEOMETRIC TOLERANCING PER: | Q.A.
MATERIAL | | SIZE A | DWG. NO. | REV

PROPRIETARY AND CONFIDENTIAL
THE INFORMATION CONTAINED IN THIS
DRAWING IS THE SOLE PROPERTY OF
<INSERT COMPANY NAME HERE>. ANY
REPRODUCTION IN PART OR AS A WHOLE
WITHOUT THE WRITTEN PERMISSION OF
<INSERT COMPANY NAME HERE> IS
PROHIBITED.

NEXT ASSY | USED ON | FINISH

APPLICATION | DO NOT SCALE DRAWING | | SCALE: 1:2 | WEIGHT: | SHEET 1 OF 4

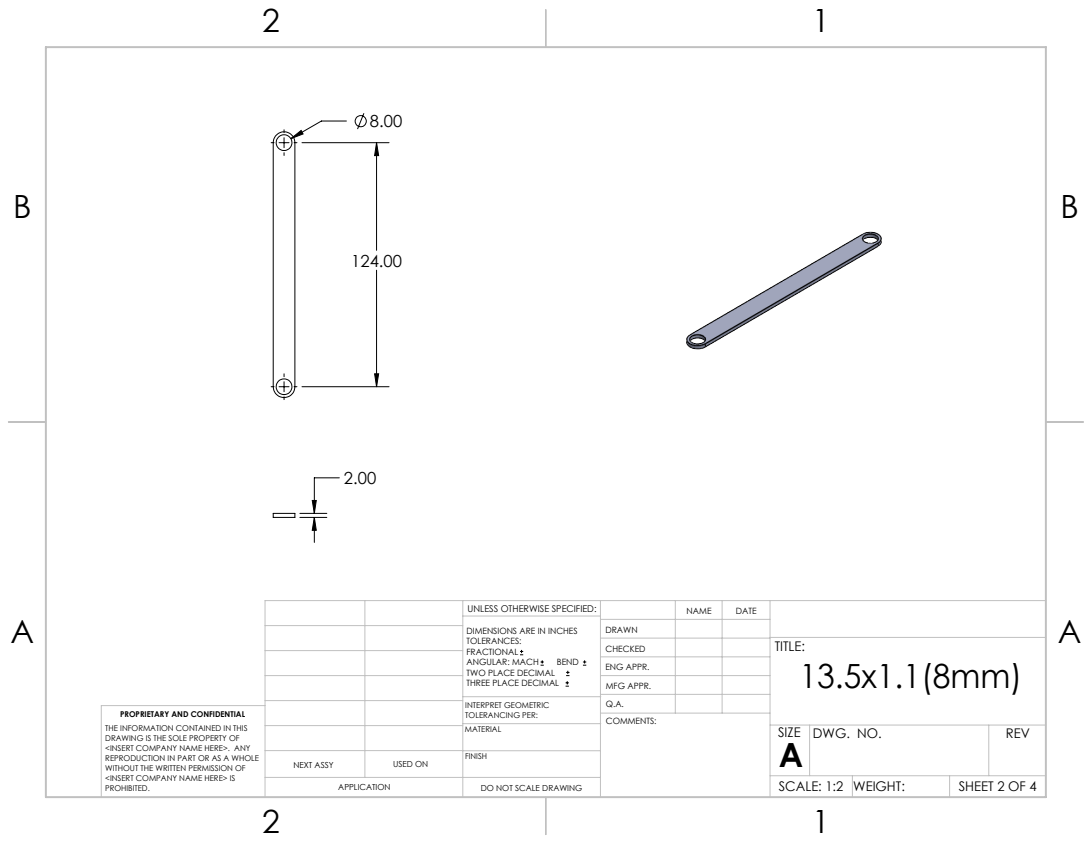
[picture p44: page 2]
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

CHECKED | | | TITLE: 13.5x1.1(8mm)

ENG APPR.
MFG APPR.

INTERPRET GEOMETRIC TOLERANCING PER: | Q.A.
MATERIAL | | SIZE A | DWG. NO. | REV

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

NEXT ASSY | USED ON | FINISH

SCALE: 1:2 | WEIGHT:

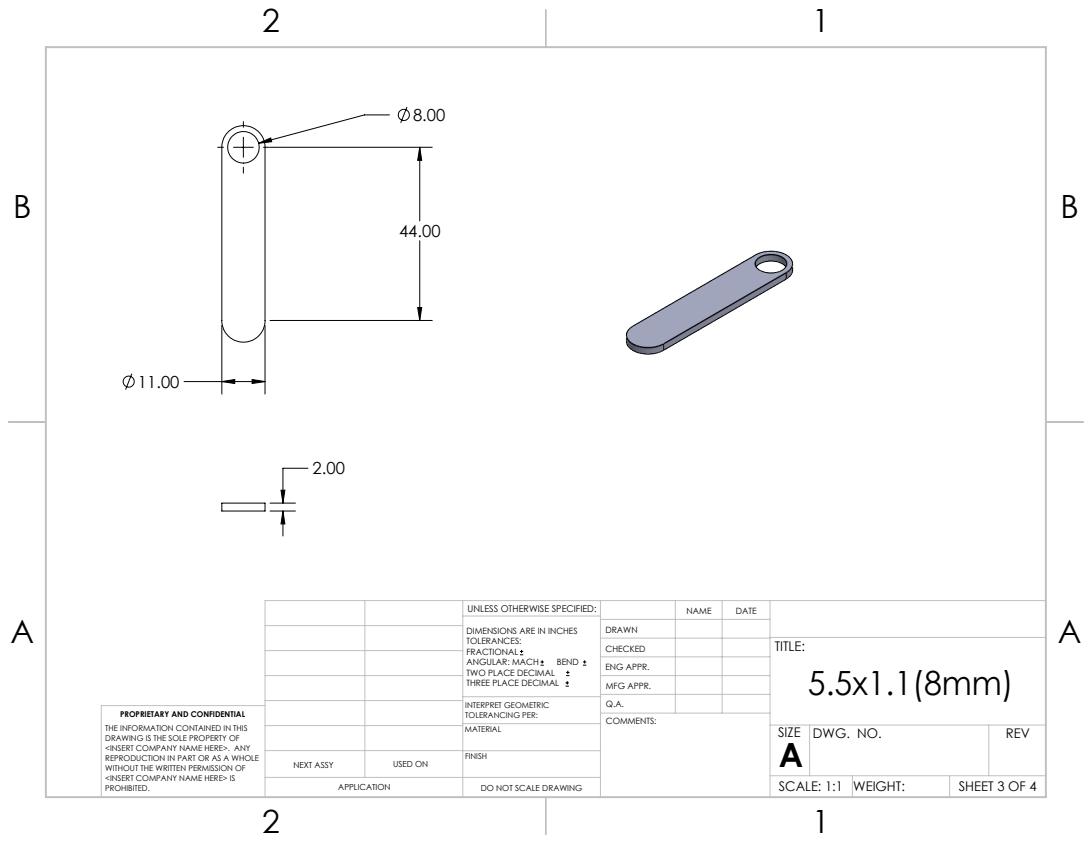
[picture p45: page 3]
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

CHECKED | | | TITLE: 5.5x1.1(8mm)

ENG APPR.
MFG APPR.

INTERPRET GEOMETRIC TOLERANCING PER: | Q.A.
MATERIAL | | SIZE A | DWG. NO. | REV

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

NEXT ASSY | USED ON | FINISH

SCALE: 1:1 | WEIGHT:

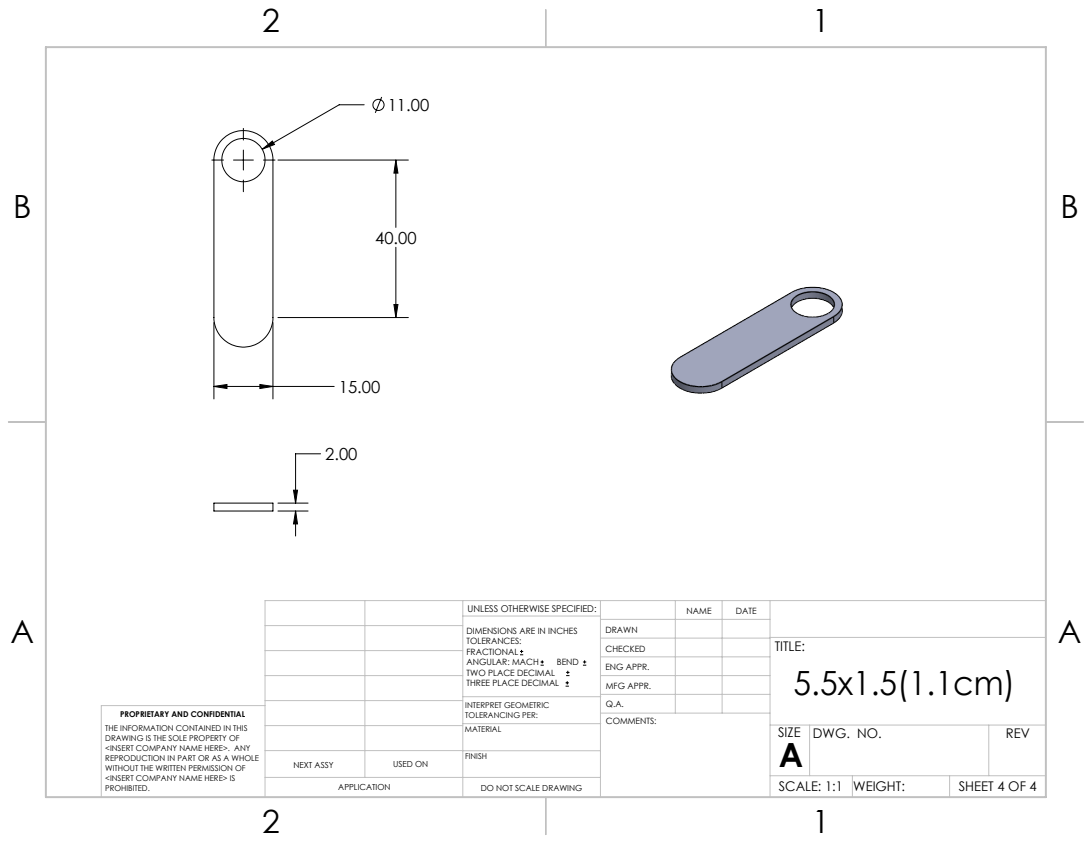
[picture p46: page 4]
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

CHECKED | | | TITLE: 5.5x1.5(1.1cm)

ENG APPR.
MFG APPR.

INTERPRET GEOMETRIC TOLERANCING PER: | Q.A.
MATERIAL | | SIZE A | DWG. NO. | REV

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

NEXT ASSY | USED ON | FINISH

SCALE: 1:1 | WEIGHT:

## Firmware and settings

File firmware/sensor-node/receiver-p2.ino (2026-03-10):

#include <SPI.h>
#include <LoRa.h>

// LoRa PHY parameters must match the transmitter exactly.
#define SF 10
#define BW 125E3
#define CR 8

void setup() {
  Serial.begin(115200);
  while (!Serial);

  if (!LoRa.begin(433E6)) {
    Serial.println("LoRa init failed!");
    while (1);
  }

  LoRa.setSpreadingFactor(SF);
  LoRa.setSignalBandwidth(BW);
  LoRa.setCodingRate4(CR);
  LoRa.setPreambleLength(8);
  LoRa.setSyncWord(0x11);
  LoRa.enableCrc();
}

void loop() {
  // parsePacket(2) uses implicit header mode expecting a fixed 2-byte payload.
  int packetSize = LoRa.parsePacket(2);
  if (packetSize == 2) {
    uint8_t buf[2];
    LoRa.readBytes(buf, 2);

    uint16_t packetData = buf[0] | (buf[1] << 8);

    // Unpack [15:6] 10-bit ID (1024 nodes max) and [5:0] distance from the 2-byte payload.
    uint16_t identifier = (packetData >> 6) & 0x3FF;
    uint8_t distance6 = packetData & 0x3F;

    float distance_cm = (float)distance6;

    int rssi = LoRa.packetRssi();
    float snr = LoRa.packetSnr();

    Serial.print("ID: "); Serial.print(identifier);
    Serial.print(" | Distance: "); Serial.print(distance_cm); Serial.print(" cm");
    Serial.print(" | RSSI: "); Serial.print(rssi); Serial.print(" dBm");
    Serial.print(" | SNR: "); Serial.println(snr);
  }
}

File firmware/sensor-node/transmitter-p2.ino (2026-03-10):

#include <SPI.h>
#include <LoRa.h>

const uint16_t identifier = 12;

#define TRIG_PIN 4
#define ECHO_PIN 3
#define TIMEOUT 30000

// LoRa PHY parameters must match the receiver exactly.
#define SF 10
#define BW 125E3
#define CR 8
#define TX_POWER 20

void setup() {
  pinMode(TRIG_PIN, OUTPUT);
  pinMode(ECHO_PIN, INPUT);

  if (!LoRa.begin(433E6)) {
    while (1);
  }

  LoRa.setSpreadingFactor(SF);
  LoRa.setSignalBandwidth(BW);
  LoRa.setCodingRate4(CR);
  LoRa.setPreambleLength(8);
  LoRa.setSyncWord(0x11);
  LoRa.enableCrc();
}

void loop() {
  digitalWrite(TRIG_PIN, HIGH);
  delayMicroseconds(10);
  digitalWrite(TRIG_PIN, LOW);

  uint32_t duration_us = pulseIn(ECHO_PIN, HIGH, TIMEOUT);
  // Single-step ultrasonic scale: microseconds of round-trip echo -> centimeters.
  float distance_cm = duration_us * 0.008575f;

  // Saturate to 6 bits so the value always fits in 0..63 before packing.
  uint8_t distance6 = (distance_cm > 63) ? 63 : (uint8_t)distance_cm;

  // Packet layout: [15:6] 10-bit ID (1024 nodes max), [5:0] 6-bit distance.
  uint16_t packetData = ((identifier & 0x3FF) << 6) | (distance6 & 0x3F);

  // beginPacket(1) enables implicit header mode on TX for fixed 2-byte payloads.
  LoRa.beginPacket(1);
  LoRa.write((uint8_t*)&packetData, 2);
  LoRa.endPacket();
}
